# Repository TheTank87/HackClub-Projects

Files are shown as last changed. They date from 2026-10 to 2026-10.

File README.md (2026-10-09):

# Starbie PCB
This Starbie board will be my first project and I will program it to do some cool things.

Screenshot 2026-10-08 at 9 03 29 PM

Finished project design. More notes in the JOURNAL.

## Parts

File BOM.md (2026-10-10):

# Starbie – bill of materials

<!-- Generated by Half Life from project cmuvka4jt00yv01pye26lm747. Edits here are overwritten on the next sync. -->
<!-- Generated: 2026-10-10T00:50:09.088Z -->

> [!NOTE]
> This parts list is mirrored from [Half Life](https://halflife.hackclub.com). Editing it here will not change the platform's copy, and the next sync overwrites this file.

| Week | Tier | Parts funding |
| --- | --- | --- |
| Week 1 | Tier 1 | $30.00 |

| Part | What it's for | Qty | Unit | Total | Vendor |
| --- | --- | --- | --- | --- | --- |
| [XIAO ESP32 c3](https://seeedstudio.com/Seeed-XIAO-ESP32C3-p-5431.html) | Wi-Fi and BLE wireless connections. | 1 | $5.00 | $5.00 | [LCSC](https://seeedstudio.com/Seeed-XIAO-ESP32C3-p-5431.html) |
| [0.96 OLED](https://www.amazon.com/dp/B0GBVWBWCR) | The screen | 1 | $2.50 | $2.50 | [Amazon](https://www.amazon.com/dp/B0GBVWBWCR) |
| [MPU6050](https://www.amazon.com/dp/B0943SGP34) | Another sensor module Accelerometer | 1 | $2.29 | $2.29 | [Amazon](https://www.amazon.com/dp/B0943SGP34) |
| [DHT11](https://www.amazon.com/dp/B0BLG7R99R) | Temperature and humidity sensor. | 1 | $3.33 | $3.33 | [Amazon](https://www.amazon.com/dp/B0BLG7R99R) |
| [MX Switches](https://www.amazon.com/dp/B0FQP8VYX4) | Switches for the keycaps | 4 | $0.18 | $0.72 | [Amazon](https://www.amazon.com/dp/B0FQP8VYX4) |
| [Keycaps](https://www.amazon.com/dp/B0CQ2VLMVY) | The caps for the switches | 4 | $0.60 | $2.40 | [Amazon](https://www.amazon.com/dp/B0CQ2VLMVY) |
| [10k Resistor](https://www.amazon.com/dp/B0B4JFPHTW) | A resistor | 1 | $0.05 | $0.05 | [Amazon](https://www.amazon.com/dp/B0B4JFPHTW) |
| [PCB](https://jlcpcb.com/) | The board | 1 | $10.00 | $10.00 | [JLC](https://jlcpcb.com/) |
| **Parts subtotal** | — | — | — | **$26.29** | — |
| **Tax & shipping** | — | — | — | **$0.00** | — |
| **Total** | — | — | — | **$26.29** | — |

$3.71 left of the tier's funding.

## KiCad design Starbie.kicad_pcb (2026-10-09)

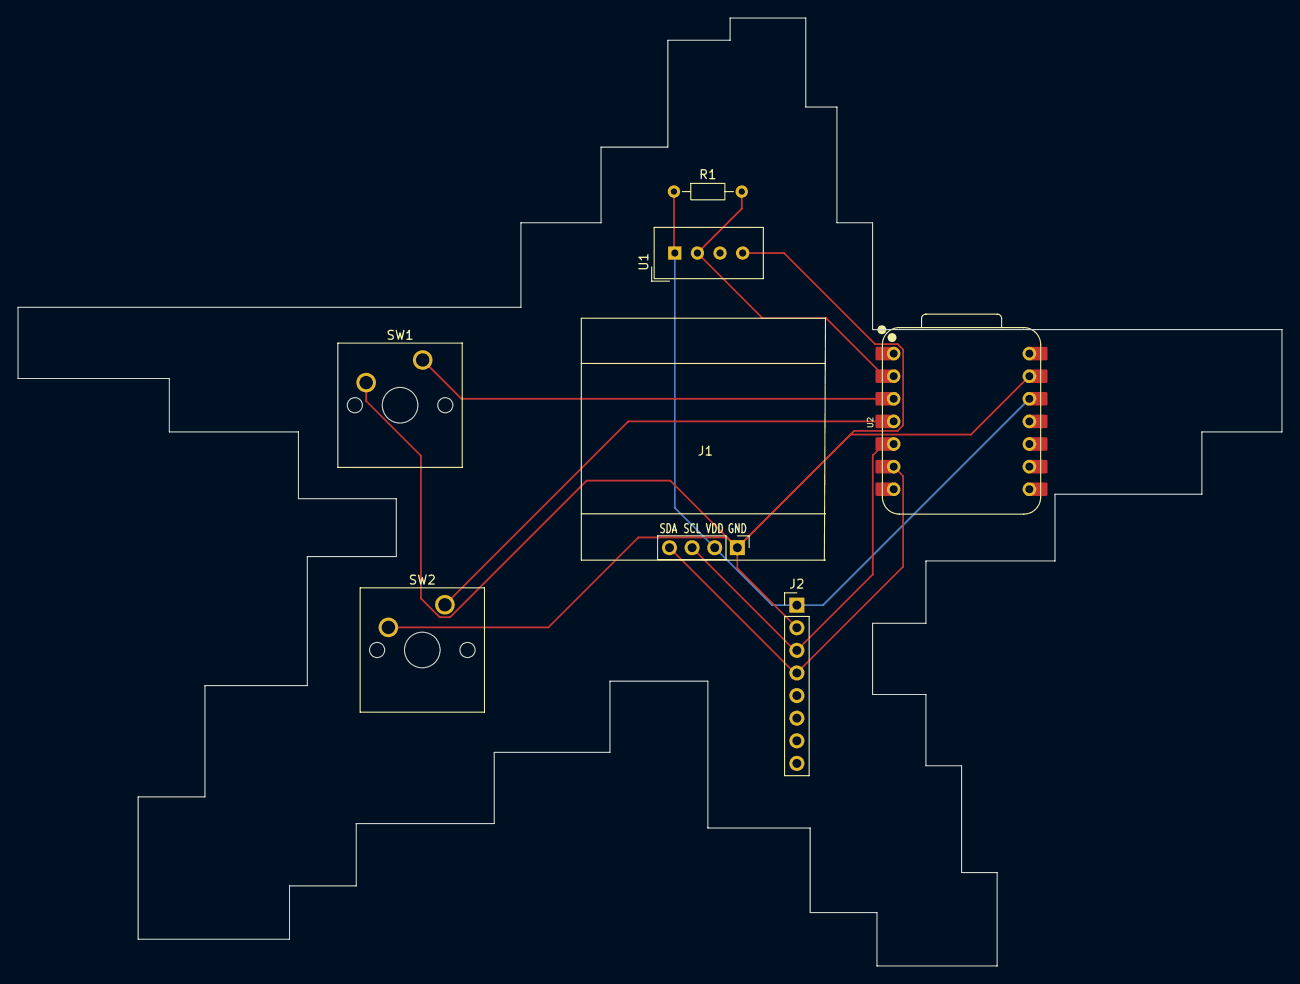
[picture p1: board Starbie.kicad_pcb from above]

Board: 2 copper layers, 142.0 x 106.5 mm, 7 parts (0 on the bottom side), 7 nets.

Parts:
J1: Conn_01x04_Pin; Display_128x64_096_I2C
J2: Conn_01x08_Pin; PinHeader_1x08_P2.54mm_Vertical
R1: 10K; R_Axial_DIN0204_L3.6mm_D1.6mm_P7.62mm_Horizontal
SW1, SW2: SW_Push; SW_Cherry_MX_1.00u_PCB
U1: DHT11; Aosong_DHT11_5.5x12.0_P2.54mm
U2: XIAO-ESP32-C3-SMD; XIAO-ESP32-C6-DIP

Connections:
+3.3V: J1.2, J2.1, R1.1, U1.1 (VDD), U2.12 (3V3_OUT)
/DHT11 DATA: R1.2, U1.2 (DATA), U2.2 (D1)
/GPIO2: SW1.1 (C), U2.3 (D2)
/GPIO3: SW2.1 (C), U2.4 (D3)
/SCL: J1.3, J2.3, U2.5 (D4)
/SDA: J1.4, J2.4, U2.6 (D5)
GND: J1.1, J2.2, SW1.2 (D), SW2.2 (D), U1.4 (GND), U2.13 (GND)

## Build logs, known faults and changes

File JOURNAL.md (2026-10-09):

# Starbie – devlog

<!-- Generated by Half Life from project cmuvka4jt00yv01pye26lm747. Edits here are overwritten on the next sync. -->
<!-- Generated: 2026-10-09T19:42:22.943Z -->

> [!NOTE]
> This devlog is mirrored from [Half Life](https://halflife.hackclub.com). Editing it here will not change the platform's copy, and the next sync overwrites this file.

> A tiny motion-controlled digital pet, basically a desktop Tamagotchi. Totally not a Starboy.

| Week | Tier | Hours logged | Entries |
| --- | --- | --- | --- |
| Week 1 | Tier 1 | 20h | 4 |

## Contents

1. [2026-10-07 – I installed all the apps needed to start making my Starbie project. I installed Kicad and got my project up. Now I started making the schematic. I have no idea what I was doing at first, but a little](#2026-10-07-i-installed-all-the-apps-needed-to-start-making-m)
2. [2026-10-08 – Ok this took me a really long time, because I was a little sick, so I couldn't figure some easy things out. I was figuring where the heck you get these blue Xs from, then I realized pressing Q creates](#2026-10-08-ok-this-took-me-a-really-long-time-because-i-was-)
3. [2026-10-09 – OK this was kinda dumb of me, but when I installed Ardunio IDE I couldn't find the tab menu. I was relatively new to the macbook and my windows brain kept thinking that apps always come with a tab on](#2026-10-09-ok-this-was-kinda-dumb-of-me-but-when-i-installed)
4. [2026-10-09 – ![Screenshot 2026-10-09 at 12.41.27 PM](https://halflife.hackclub-assets.com/hackclub-half-life/sessions/ZDAOO2ufQE4izwUEwNePt1JFUHVP4iKp/82490ac1568686b8695ba1480d59f20e000a1c176753b12b91733b1bdf9a68](#2026-10-09-screenshot-2026-10-09-at-124127-pmhttpshalflifeha)

## Design

### 2026-10-07 – I installed all the apps needed to start making my Starbie project. I installed Kicad and got my project up. Now I started making the schematic. I have no idea what I was doing at first, but a little

**2h**

I installed all the apps needed to start making my Starbie project. I installed Kicad and got my project up. Now I started making the schematic. I have no idea what I was doing at first, but a little research helped me be able to navigate Kicad on MacOS. It turns out that Kicad on Mac was a lot more inconvenient as you can only access the foot print and symbol libraries using hot keys. I'm genuinely surprised that they didn't include the tabber on the tab like the Linux and Windows version.

Screenshot 2026-10-07 at 11.06.17 AM

Screenshot 2026-10-07 at 11.06.34 AM

### 2026-10-08 – Ok this took me a really long time, because I was a little sick, so I couldn't figure some easy things out. I was figuring where the heck you get these blue Xs from, then I realized pressing Q creates

**4h**

Ok this took me a really long time, because I was a little sick, so I couldn't figure some easy things out. I was figuring where the heck you get these blue Xs from, then I realized pressing Q creates them; big brainfart. Then I finished the schematic and I was really happy. However, I then started working on the PCB editor and I spent most of my time designing a board that would fit all the parts as well as giving those connector lines the best possible path. Oh yeah, don't forget to mention the BUTTONS. I'd say the figuring out the buttons was my greatest achievement yet at trouble-shooting. The Sw2 button was connecting incorrectly on the pcb editor, then I realized it was in form B not A, and I Was like BRO. so I changed it and it connects well now...

Screenshot 2026-10-08 at 9.19.19 AM

Screenshot 2026-10-08 at 9.19.30 AM

Screenshot 2026-10-08 at 9.19.45 AM

Screenshot 2026-10-08 at 9.21.23 AM

### 2026-10-09 – OK this was kinda dumb of me, but when I installed Ardunio IDE I couldn't find the tab menu. I was relatively new to the macbook and my windows brain kept thinking that apps always come with a tab on

**4h**

OK this was kinda dumb of me, but when I installed Ardunio IDE I couldn't find the tab menu. I was relatively new to the macbook and my windows brain kept thinking that apps always come with a tab on the actual app window. However, that's different for the macbook, because it's on the very top next to the apple icon like built in buttons. When I realized that it was a big forehead slap. Anyways, got things to to work now and now I'm waiting for my board! Oh yeah, also finished PCB design and came to a good conclusion, I created my star shape and got things to wire up correctly. The blue ones took a while to figure out.

Screenshot 2026-10-08 at 9.02.30 PM

Screenshot 2026-10-08 at 9.02.50 PM

Screenshot 2026-10-08 at 9.03.29 PM

Screenshot 2026-10-08 at 9.03.39 PM

### 2026-10-09 – ![Screenshot 2026-10-09 at 12.41.27 PM](https://halflife.hackclub-assets.com/hackclub-half-life/sessions/ZDAOO2ufQE4izwUEwNePt1JFUHVP4iKp/82490ac1568686b8695ba1480d59f20e000a1c176753b12b91733b1bdf9a68

**10h**

Screenshot 2026-10-09 at 12.41.27 PM

Screenshot 2026-10-09 at 12.41.31 PM

Screenshot 2026-10-09 at 12.41.35 PM

Screenshot 2026-10-09 at 12.41.38 PM

Screenshot 2026-10-09 at 12.41.41 PM

Screenshot 2026-10-09 at 12.41.49 PM

Screenshot 2026-10-09 at 12.41.52 PM

I spent along hours designing on designing cool doodles for my PCB. I skipped that part so that I got the actual design part done and now with free time I can add cosmetics. I came up with 3 different pages at first of designs and they were all pretty nice. However, I like the one with the bug robot character I drew. I created that character a long time ago and it has a LOT of lore. I'll also attach a whole comic on here so that you would know where this thing came from.

Screenshot 2026-10-09 at 10.41.48 AM

Screenshot 2026-10-09 at 10.45.12 AM

Screenshot 2026-10-09 at 10.49.09 AM

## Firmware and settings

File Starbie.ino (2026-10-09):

/*
  Starbie: a tiny motion-controlled digital pet

  This is intentionally one file. Open this .ino file in Arduino IDE, edit
  the BEGINNER SETTINGS section, and upload it to a Seeed XIAO ESP32-C3.

  Install these libraries with Sketch > Include Library > Manage Libraries:
    - Adafruit GFX Library
    - Adafruit SSD1306
    - Adafruit MPU6050
    - DHT sensor library
  Arduino IDE will offer to install their dependencies too. Click Install All.
*/

#include <Wire.h>
#include <Adafruit_GFX.h>
#include <Adafruit_SSD1306.h>
#include <Adafruit_MPU6050.h>
#include <DHT.h>
#include <Preferences.h>
#include <math.h>

// =========================== BEGINNER SETTINGS ===========================
// Everything most builders will want to customize is in this one section.

// --- Your board's pins ----------------------------------------------------
// These are ESP32-C3 GPIO numbers, with the XIAO pin labels beside them.
const int I2C_SDA_PIN = 6;       // XIAO D4: OLED + MPU6050 SDA
const int I2C_SCL_PIN = 7;       // XIAO D5: OLED + MPU6050 SCL
const int DHT_PIN = 3;           // XIAO D1: DHT11 data
const int BUTTON_ONE_PIN = 4;    // XIAO D2: opens/confirms the radial menu
const int BUTTON_TWO_PIN = 5;    // XIAO D3: shows/hides stats

// Set this to false if your submission does not have a DHT11.
const bool USE_DHT11 = true;

// Most parts use these addresses. Only change them if an I2C scanner says
// your part is different (common OLED alternative: 0x3D).
const uint8_t OLED_ADDRESS = 0x3C;
const uint8_t MPU6050_ADDRESS = 0x68;

// --- Starting stats -------------------------------------------------------
// Stats are 0 to 100. They only change when you select an action or shake
// Starbie; nothing slowly drains while it sits on your desk.
const int STARTING_JOY = 70;
const int STARTING_ENERGY = 75;
const int STARTING_FULLNESS = 65;

// Set true, upload once, then set it back to false if you want a fresh pet.
const bool RESET_SAVED_PET_ON_BOOT = false;

// --- Radial menu ----------------------------------------------------------
// These four actions appear at TOP, RIGHT, BOTTOM, then LEFT in the menu.
// The last word controls the matching little visual reaction.
enum PetReaction {
  NAP_REACTION,
  JUMP_REACTION,
  HEART_REACTION,
  RUN_REACTION,
};

struct MenuItem {
  const char *label;
  int joyChange;
  int energyChange;
  int fullnessChange;
  PetReaction reaction;
};

const MenuItem MENU_ITEMS[] = {
  {"NAP",   1,  18, -4, NAP_REACTION},   // top: sleep and emit Zs
  {"PLAY", 12, -9, -5, RUN_REACTION},    // right: two fast laps + hearts
  {"FEED",  3,  2,  18, JUMP_REACTION},  // bottom: wiggle and jump
  {"PET",   7,  0,  0, HEART_REACTION},  // left: jump and emit hearts
};
const int MENU_ITEM_COUNT = sizeof(MENU_ITEMS) / sizeof(MENU_ITEMS[0]);

// --- Movement feel --------------------------------------------------------
// Bigger MENU_TILT_LIMIT makes the menu ball move less.
const float MENU_TILT_LIMIT = 6.0f;

// MPU6050 orientation: change these settings instead of rewiring your board.
// 1. If the sensor is turned 90 degrees, set SWAP_MPU_AXES to true.
// 2. If a direction feels backwards, change that direction from 1.0f to -1.0f.
const bool SWAP_MPU_AXES = false;
const float MENU_X_DIRECTION = 1.0f;
const float MENU_Y_DIRECTION = -1.0f;

// A small dead zone makes the ball rest in the center until the board is tilted.
const float MENU_CENTER_DEADZONE = 0.8f;
const float SHAKE_THRESHOLD = 7.0f;

// Shake is the only movement that has an effect outside the radial menu.
const int SHAKE_JOY_CHANGE = 5;
const int SHAKE_ENERGY_CHANGE = -2;
const int SHAKE_FULLNESS_CHANGE = -1;

// --- Your pet's bitmap and animation -------------------------------------
// This is a simplified 32 by 32, one-bit version of the supplied character.
// You can replace it with your own art later; keep these size values matched
// to the sprite array you paste in.
const int PET_SPRITE_WIDTH = 32;
const int PET_SPRITE_HEIGHT = 32;

// The pet wanders unless it is asleep. A non-nap action does a tiny shake,
// then a jump, except PLAY which runs two fast laps.
const uint16_t PET_WALK_PIXEL_MS = 70;
const uint16_t PET_PRE_JUMP_MS = 230;
const uint16_t PET_JUMP_MS = 430;
const int PET_JUMP_HEIGHT = 16;
const uint32_t NAP_DURATION_MS = 48000;  // 48 seconds: four times the old nap.
const uint16_t HEARTS_DURATION_MS = 1600;
const uint16_t PLAY_LAP_MS = 800;
const uint8_t PLAY_LAP_COUNT = 2;

// Each byte stores eight pixels, left to right. This sparse outline keeps the
// supplied creature readable on a tiny, one-bit OLED: head, eye, legs, tail,
// and a small flower-like ear accent all stay separate instead of becoming a blob.
const uint8_t PROGMEM PET_SPRITE[] = {
  0x00, 0x00, 0x00, 0x00,
  0x00, 0x00, 0x00, 0x00,
  0x00, 0x00, 0x00, 0x00,
  0x00, 0x00, 0x00, 0x00,
  0x00, 0x00, 0x00, 0x00,
  0x00, 0x00, 0x00, 0x00,
  0x00, 0x70, 0x0a, 0x00,
  0x00, 0xf8, 0x1f, 0x00,
  0x00, 0x8c, 0x3f, 0x80,
  0x00, 0x43, 0xff, 0x00,
  0x00, 0x43, 0xff, 0x00,
  0x00, 0x30, 0x7e, 0x00,
  0x00, 0x98, 0x01, 0x00,
  0x01, 0x98, 0x01, 0x80,
  0x03, 0x00, 0x10, 0xc0,
  0x03, 0x04, 0x00, 0xc0,
  0x01, 0x8b, 0x01, 0x80,
  0x01, 0xcb, 0x03, 0x80,
  0x03, 0xc0, 0x03, 0xc0,
  0x03, 0xc0, 0x03, 0xc0,
  0x01, 0xc0, 0x03, 0x80,
  0x01, 0x80, 0x01, 0x80,
  0x00, 0x60, 0x06, 0x00,
  0x00, 0x3f, 0xfc, 0x00,
  0x00, 0x7f, 0xfe, 0x00,
  0x00, 0x70, 0x0e, 0x00,
  0x00, 0x00, 0x00, 0x00,
  0x00, 0x00, 0x00, 0x00,
  0x00, 0x00, 0x00, 0x00,
  0x00, 0x00, 0x00, 0x00,
  0x00, 0x00, 0x00, 0x00,
  0x00, 0x00, 0x00, 0x00,
};
// ===========================================================================
// You can read below without needing to understand every line. The rest of
// the sketch handles buttons, sensors, drawing, and saving automatically.

const int SCREEN_WIDTH = 128;
const int SCREEN_HEIGHT = 64;
const int MENU_CENTER_X = 64;
const int MENU_CENTER_Y = 32;
const int MENU_ITEM_X[] = {64, 108, 64, 20};
const int MENU_ITEM_Y[] = {12, 32, 53, 32};
const int MENU_BALL_X_RANGE = 37;
const int MENU_BALL_Y_RANGE = 22;
const uint16_t BUTTON_DEBOUNCE_MS = 30;
const uint16_t MPU_READ_INTERVAL_MS = 30;
const uint16_t DHT_READ_INTERVAL_MS = 2200;
const uint16_t SHAKE_COOLDOWN_MS = 650;
const float STANDARD_GRAVITY = 9.80665f;

Adafruit_SSD1306 display(SCREEN_WIDTH, SCREEN_HEIGHT, &Wire, -1);
Adafruit_MPU6050 mpu;
DHT dht(DHT_PIN, DHT11);
Preferences preferences;

struct PetState {
  int joy;
  int energy;
  int fullness;
};

struct ButtonState {
  int pin;
  bool stableState;
  bool lastRawState;
  uint32_t lastChangedAt;
};

enum View {
  PET_VIEW,
  MENU_VIEW,
  STATS_VIEW,
};

PetState pet = {STARTING_JOY, STARTING_ENERGY, STARTING_FULLNESS};
ButtonState buttonOne = {BUTTON_ONE_PIN, HIGH, HIGH, 0};
ButtonState buttonTwo = {BUTTON_TWO_PIN, HIGH, HIGH, 0};
View currentView = PET_VIEW;

bool mpuFound = false;
bool dhtFound = false;
float accelerationX = 0.0f;
float accelerationY = 0.0f;
float accelerationZ = STANDARD_GRAVITY;
float temperatureC = NAN;
float humidity = NAN;
float menuBallX = MENU_CENTER_X;
float menuBallY = MENU_CENTER_Y;
float menuCenterAccelerationX = 0.0f;
float menuCenterAccelerationY = 0.0f;
int selectedMenuItem = -1;
uint32_t lastMpuReadAt = 0;
uint32_t lastDhtReadAt = 0;
uint32_t lastShakeAt = 0;
uint32_t shakeAnimationEndsAt = 0;
uint32_t petJumpStartedAt = 0;
uint32_t nappingUntil = 0;
uint32_t heartAnimationEndsAt = 0;
uint32_t playRunStartedAt = 0;
int nappingPetX = 0;

int petWalkingX(uint32_t now);

int keepInRange(int value, int smallest, int largest) {
  return constrain(value, smallest, largest);
}

void changePet(int joyChange, int energyChange, int fullnessChange) {
  pet.joy = keepInRange(pet.joy + joyChange, 0, 100);
  pet.energy = keepInRange(pet.energy + energyChange, 0, 100);
  pet.fullness = keepInRange(pet.fullness + fullnessChange, 0, 100);
}

void loadPet() {
  preferences.begin("starbie", false);
  if (RESET_SAVED_PET_ON_BOOT) {
    preferences.clear();
  }
  pet.joy = preferences.getInt("joy", STARTING_JOY);
  pet.energy = preferences.getInt("energy", STARTING_ENERGY);
  pet.fullness = preferences.getInt("full", STARTING_FULLNESS);
}

void savePet() {
  preferences.putInt("joy", pet.joy);
  preferences.putInt("energy", pet.energy);
  preferences.putInt("full", pet.fullness);
}

void setUpButton(ButtonState &button) {
  pinMode(button.pin, INPUT_PULLUP);
  button.stableState = digitalRead(button.pin);
  button.lastRawState = button.stableState;
  button.lastChangedAt = millis();
}

// Returns true exactly once for each press, even if the switch bounces.
bool wasPressed(ButtonState &button) {
  const bool rawState = digitalRead(button.pin);
  const uint32_t now = millis();

  if (rawState != button.lastRawState) {
    button.lastRawState = rawState;
    button.lastChangedAt = now;
  }

  if (rawState != button.stableState &&
      now - button.lastChangedAt >= BUTTON_DEBOUNCE_MS) {
    button.stableState = rawState;
    return button.stableState == LOW;
  }

  return false;
}

void updateMpu() {
  if (!mpuFound || millis() - lastMpuReadAt < MPU_READ_INTERVAL_MS) {
    return;
  }
  lastMpuReadAt = millis();

  sensors_event_t acceleration;
  sensors_event_t gyro;
  sensors_event_t sensorTemperature;
  mpu.getEvent(&acceleration, &gyro, &sensorTemperature);
  accelerationX = acceleration.acceleration.x;
  accelerationY = acceleration.acceleration.y;
  accelerationZ = acceleration.acceleration.z;
}

void updateDht() {
  if (!dhtFound || millis() - lastDhtReadAt < DHT_READ_INTERVAL_MS) {
    return;
  }
  lastDhtReadAt = millis();

  const float newHumidity = dht.readHumidity();
  const float newTemperatureC = dht.readTemperature();
  if (!isnan(newHumidity)) {
    humidity = newHumidity;
  }
  if (!isnan(newTemperatureC)) {
    temperatureC = newTemperatureC;
  }
}

int petWalkingX(uint32_t now) {
  const int farthestX = SCREEN_WIDTH - PET_SPRITE_WIDTH;
  const uint32_t roundTrip = static_cast<uint32_t>(farthestX) * 2;
  const uint32_t step = (now / PET_WALK_PIXEL_MS) % roundTrip;
  return step <= farthestX ? step : roundTrip - step;
}

uint32_t playRunDuration() {
  return static_cast<uint32_t>(PLAY_LAP_MS) * PLAY_LAP_COUNT;
}

bool isNapping() {
  return nappingUntil != 0 && millis() < nappingUntil;
}

bool isPlaying() {
  return playRunStartedAt != 0 && millis() - playRunStartedAt < playRunDuration();
}

int playRunX(uint32_t now) {
  const int farthestX = SCREEN_WIDTH - PET_SPRITE_WIDTH;
  const uint32_t lapAge = (now - playRunStartedAt) % PLAY_LAP_MS;
  const float progress = static_cast<float>(lapAge) / PLAY_LAP_MS;
  return progress < 0.5f ? static_cast<int>(progress * 2.0f * farthestX)
                         : static_cast<int>((1.0f - progress) * 2.0f * farthestX);
}

void updatePetTimers() {
  if (nappingUntil != 0 && !isNapping()) {
    nappingUntil = 0;  // The pet wakes naturally when its nap time is over.
  }
  if (playRunStartedAt != 0 && !isPlaying()) {
    playRunStartedAt = 0;  // PLAY is exactly two left-to-right-to-left laps.
  }
}

// While the menu is open, the MPU6050 acts like a tiny air mouse. The position
// at the instant Button 1 opens the menu becomes the center for that menu use.
void updateMenuBall() {
  float xTilt = accelerationX - menuCenterAccelerationX;
  float yTilt = accelerationY - menuCenterAccelerationY;

  if (SWAP_MPU_AXES) {
    const float oldXTilt = xTilt;
    xTilt = yTilt;
    yTilt = oldXTilt;
  }
  xTilt = constrain(xTilt * MENU_X_DIRECTION, -MENU_TILT_LIMIT, MENU_TILT_LIMIT);
  yTilt = constrain(yTilt * MENU_Y_DIRECTION, -MENU_TILT_LIMIT, MENU_TILT_LIMIT);
  const float targetX = MENU_CENTER_X + (xTilt / MENU_TILT_LIMIT) * MENU_BALL_X_RANGE;
  const float targetY = MENU_CENTER_Y + (yTilt / MENU_TILT_LIMIT) * MENU_BALL_Y_RANGE;

  // This small amount of smoothing makes the ball feel less jittery.
  menuBallX += (targetX - menuBallX) * 0.20f;
  menuBallY += (targetY - menuBallY) * 0.20f;

  // The menu has four full sectors, not four tiny targets. Any tilt direction
  // past the center dead zone selects its matching top/right/bottom/left action.
  if (fabsf(xTilt) < MENU_CENTER_DEADZONE && fabsf(yTilt) < MENU_CENTER_DEADZONE) {
    selectedMenuItem = -1;
  } else if (fabsf(xTilt) > fabsf(yTilt)) {
    selectedMenuItem = xTilt > 0.0f ? 1 : 3;  // right or left
  } else {
    selectedMenuItem = yTilt > 0.0f ? 2 : 0;  // bottom or top
  }
}

void checkForShake() {
  if (!mpuFound || currentView != PET_VIEW) {
    return;
  }

  const float magnitude = sqrtf(accelerationX * accelerationX +
                                accelerationY * accelerationY +
                                accelerationZ * accelerationZ);
  const uint32_t now = millis();
  if (fabsf(magnitude - STANDARD_GRAVITY) >= SHAKE_THRESHOLD &&
      now - lastShakeAt >= SHAKE_COOLDOWN_MS) {
    lastShakeAt = now;
    nappingUntil = 0;  // A shake wakes a sleeping pet right away.
    shakeAnimationEndsAt = now + 350;
    changePet(SHAKE_JOY_CHANGE, SHAKE_ENERGY_CHANGE, SHAKE_FULLNESS_CHANGE);
    savePet();
  }
}

void openMenu() {
  currentView = MENU_VIEW;
  selectedMenuItem = -1;
  menuBallX = MENU_CENTER_X;
  menuBallY = MENU_CENTER_Y;
  // Calibrate here so every menu starts from however the builder is holding it.
  menuCenterAccelerationX = accelerationX;
  menuCenterAccelerationY = accelerationY;
}

void chooseMenuItem() {
  if (selectedMenuItem == -1) {
    return;  // Keep the menu open until the ball reaches a choice.
  }

  const MenuItem &item = MENU_ITEMS[selectedMenuItem];
  changePet(item.joyChange, item.energyChange, item.fullnessChange);
  savePet();
  const uint32_t now = millis();
  nappingUntil = 0;
  heartAnimationEndsAt = 0;
  playRunStartedAt = 0;

  if (item.reaction == NAP_REACTION) {
    petJumpStartedAt = 0;
    nappingPetX = petWalkingX(now);
    nappingUntil = now + NAP_DURATION_MS;
  } else if (item.reaction == RUN_REACTION) {
    petJumpStartedAt = 0;
    playRunStartedAt = now;
    heartAnimationEndsAt = now + playRunDuration();
  } else {
    // A confirmed action gets a little anticipation shake before the jump.
    petJumpStartedAt = now;
    if (item.reaction == HEART_REACTION) {
      heartAnimationEndsAt = now + HEARTS_DURATION_MS;
    }
  }
  currentView = PET_VIEW;
}

void handleButtons() {
  if (wasPressed(buttonOne)) {
    if (currentView == MENU_VIEW) {
      chooseMenuItem();
    } else {
      openMenu();
    }
  }

  if (wasPressed(buttonTwo)) {
    // Button 2 never changes the pet. It only lets you peek at the values.
    currentView = currentView == STATS_VIEW ? PET_VIEW : STATS_VIEW;
  }
}

void drawHeart(int x, int y) {
  // A tiny seven-pixel-wide heart that stays crisp on the OLED.
  display.fillRect(x - 2, y, 2, 2, SSD1306_WHITE);
  display.fillRect(x + 1, y, 2, 2, SSD1306_WHITE);
  display.fillRect(x - 3, y + 2, 7, 2, SSD1306_WHITE);
  display.fillRect(x - 2, y + 4, 5, 1, SSD1306_WHITE);
  display.fillRect(x - 1, y + 5, 3, 1, SSD1306_WHITE);
  display.drawPixel(x, y + 6, SSD1306_WHITE);
}

void drawHearts(uint32_t now, int petX, int petY) {
  if (now >= heartAnimationEndsAt) {
    return;
  }

  const float progress =
      1.0f - static_cast<float>(heartAnimationEndsAt - now) / HEARTS_DURATION_MS;
  const int rise = static_cast<int>(progress * 18.0f);
  drawHeart(petX + 10, petY - 3 - rise);
  drawHeart(petX + 22, petY - 9 - rise / 2);
}

void drawSleepZs(uint32_t now, int petX, int petY) {
  // The Zs float upward, then loop back down while the pet is napping.
  const int rise = static_cast<int>((now / 300UL) % 15UL);
  display.setTextSize(1);
  display.setTextColor(SSD1306_WHITE);
  display.setCursor(petX + 23, petY - 2 - rise);
  display.print("z");
  display.setCursor(petX + 28, petY - 8 - rise / 2);
  display.print("z");
}

void drawPet() {
  display.clearDisplay();

  const uint32_t now = millis();
  int petX = isNapping() ? nappingPetX : petWalkingX(now);
  if (isPlaying()) {
    petX = playRunX(now);
  }
  int petY = SCREEN_HEIGHT - PET_SPRITE_HEIGHT;

  // The pet always wanders except during a nap; PLAY temporarily takes over.
  if (now < shakeAnimationEndsAt) {
    petX += static_cast<int>(sinf(now / 18.0f) * 3.0f);
  }

  if (!isNapping() && petJumpStartedAt != 0) {
    const uint32_t animationAge = now - petJumpStartedAt;

    if (animationAge < PET_PRE_JUMP_MS) {
      petX += static_cast<int>(sinf(now / 16.0f) * 3.0f);
    } else if (animationAge < PET_PRE_JUMP_MS + PET_JUMP_MS) {
      const float jumpProgress =
          static_cast<float>(animationAge - PET_PRE_JUMP_MS) / PET_JUMP_MS;
      petY -= static_cast<int>(sinf(jumpProgress * PI) * PET_JUMP_HEIGHT);
    } else {
      petJumpStartedAt = 0;
    }
  }

  petX = constrain(petX, 0, SCREEN_WIDTH - PET_SPRITE_WIDTH);
  display.drawBitmap(petX, petY, PET_SPRITE, PET_SPRITE_WIDTH, PET_SPRITE_HEIGHT,
                     SSD1306_WHITE);

  if (isNapping()) {
    drawSleepZs(now, petX, petY);
  }
  drawHearts(now, petX, petY);
}

void drawMenuItem(int item) {
  const int boxWidth = 33;
  const int boxHeight = 12;
  const int boxX = MENU_ITEM_X[item] - boxWidth / 2;
  const int boxY = MENU_ITEM_Y[item] - boxHeight / 2;
  const bool isSelected = item == selectedMenuItem;

  if (isSelected) {
    display.fillRoundRect(boxX, boxY, boxWidth, boxHeight, 3, SSD1306_WHITE);
    display.setTextColor(SSD1306_BLACK);
  } else {
    display.drawRoundRect(boxX, boxY, boxWidth, boxHeight, 3, SSD1306_WHITE);
    display.setTextColor(SSD1306_WHITE);
  }

  display.setTextSize(1);
  const int labelLength = strlen(MENU_ITEMS[item].label);
  display.setCursor(MENU_ITEM_X[item] - labelLength * 3, MENU_ITEM_Y[item] - 3);
  display.print(MENU_ITEMS[item].label);
  display.setTextColor(SSD1306_WHITE);
}

void drawMenu() {
  display.clearDisplay();
  // The two diagonal lines divide the screen into four big selection sectors.
  display.drawLine(0, 0, SCREEN_WIDTH - 1, SCREEN_HEIGHT - 1, SSD1306_WHITE);
  display.drawLine(0, SCREEN_HEIGHT - 1, SCREEN_WIDTH - 1, 0, SSD1306_WHITE);
  for (int item = 0; item < MENU_ITEM_COUNT; item++) {
    drawMenuItem(item);
  }

  display.drawCircle(MENU_CENTER_X, MENU_CENTER_Y, 11, SSD1306_WHITE);
  display.fillCircle(static_cast<int>(menuBallX), static_cast<int>(menuBallY), 4,
                     SSD1306_WHITE);
}

void drawStatBar(int y, const char *label, int value) {
  display.setTextSize(1);
  display.setTextColor(SSD1306_WHITE);
  display.setCursor(4, y);
  display.print(label);
  display.drawRect(48, y, 57, 8, SSD1306_WHITE);
  display.fillRect(49, y + 1, map(value, 0, 100, 0, 55), 6, SSD1306_WHITE);
  display.setCursor(109, y);
  display.print(value);
}

void drawStats() {
  display.clearDisplay();
  drawStatBar(5, "JOY", pet.joy);
  drawStatBar(20, "ENERGY", pet.energy);
  drawStatBar(35, "FULL", pet.fullness);

  display.setCursor(4, 53);
  if (!isnan(temperatureC)) {
    display.print("TEMP ");
    display.print(static_cast<int>(temperatureC));
    display.print("C");
  } else {
    display.print("TEMP --");
  }

  display.setCursor(76, 53);
  if (!isnan(humidity)) {
    display.print("H ");
    display.print(static_cast<int>(humidity));
    display.print("%");
  } else {
    display.print("H --");
  }
}

void drawCurrentView() {
  if (currentView == MENU_VIEW) {
    drawMenu();
  } else if (currentView == STATS_VIEW) {
    drawStats();
  } else {
    drawPet();
  }
  display.display();
}

void setup() {
  Serial.begin(115200);
  Wire.begin(I2C_SDA_PIN, I2C_SCL_PIN);
  setUpButton(buttonOne);
  setUpButton(buttonTwo);
  loadPet();

  if (!display.begin(SSD1306_SWITCHCAPVCC, OLED_ADDRESS)) {
    Serial.println("OLED not found. Check power, GND, SDA, SCL, and address.");
    while (true) {
      delay(10);
    }
  }

  mpuFound = mpu.begin(MPU6050_ADDRESS, &Wire);
  if (mpuFound) {
    mpu.setAccelerometerRange(MPU6050_RANGE_8_G);
    mpu.setGyroRange(MPU6050_RANGE_500_DEG);
    mpu.setFilterBandwidth(MPU6050_BAND_21_HZ);
  } else {
    Serial.println("MPU6050 not found. The menu will not move until it is connected.");
  }

  if (USE_DHT11) {
    dht.begin();
    dhtFound = true;
  }

  drawCurrentView();
}

void loop() {
  updateMpu();
  updateDht();
  updatePetTimers();
  handleButtons();

  if (currentView == MENU_VIEW) {
    updateMenuBall();
  } else {
    checkForShake();
  }

  drawCurrentView();
  delay(16);  // Smooth display updates without making the code complicated.
}

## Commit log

2026-10-06 Add initial README for Starbie PCB project
2026-10-09 Added required files.
    [Starbie.kicad_pcb, Starbie.kicad_sch]
